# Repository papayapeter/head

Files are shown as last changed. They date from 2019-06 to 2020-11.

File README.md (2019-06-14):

# head
a head that moves it's face and breathes

documentation: [https://zenogries.com/portfolio/iamnotyourtool/](https://zenogries.com/portfolio/iamnotyourtool/)

## software
* arduino code that moves the motors and plays the sounds
* arduino code to find the minimum and maximum positions of the motors
* processing code to convert after effects tracking (of jaw and eyebrows) keyframes to an c++ array (AnimationData.h) so kind of a poor persons motion capture

## libraries
* [AccelStepper](http://www.airspayce.com/mikem/arduino/AccelStepper/) by Mike McCauley

## hardware
* [teensy 3.2](https://www.pjrc.com/teensy/teensyLC.html)
* [teensy audio adapter](https://www.pjrc.com/store/teensy3_audio.html)
* [a4988 stepper driver](https://www.pololu.com/product/1182)
* [nema 17 stepper](https://www.ebay.de/itm/Nema-17-Stepper-Motor-Schrittmotor-26Ncm-12V-0-4A-4-wire-1m-cable-3D-Printer/392163408983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)
* carrier "sceleton" designed by me
* custom circuit boards

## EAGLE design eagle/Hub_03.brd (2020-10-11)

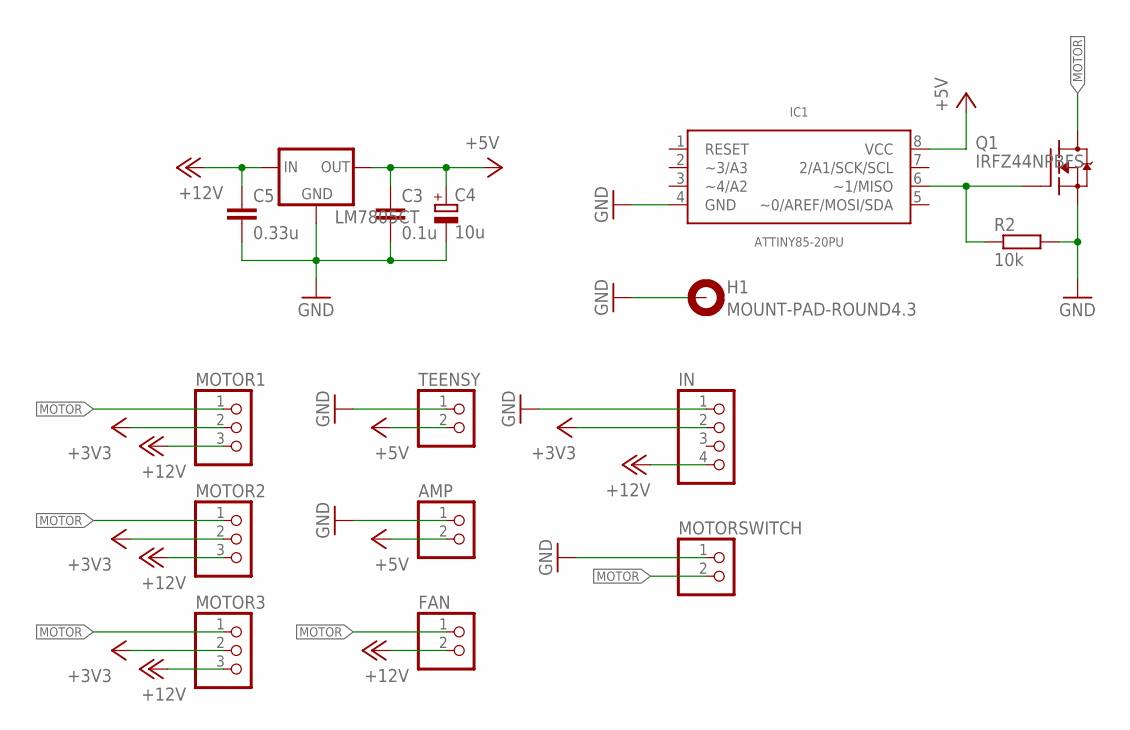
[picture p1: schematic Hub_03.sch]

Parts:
AMP: PINHD-1X2; 1X02
C3: 0.1u; C025-024X044
C4: 10u; E2,5-6E
C5: 0.33u; C025-024X044
FAN: PINHD-1X2; 1X02
H1: MOUNT-PAD-ROUND4.3; 4,3-PAD
IC1: ATTINY85-20PU; DIP08
IN: PINHD-1X4; 1X04
LM7805CT: 78XXS
MOTOR1, MOTOR2, MOTOR3: PINHD-1X3; 1X03
MOTORSWITCH: PINHD-1X2; 1X02
Q1: IRFZ44NPBFS; TO220-3S
R2: 10k; 0204/7
TEENSY: PINHD-1X2; 1X02

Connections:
+3V3: IN.2, MOTOR1.2, MOTOR2.2, MOTOR3.2
+5V: AMP.2, C3.1, C4.+, IC1.8 (VCC), LM7805CT.OUT, TEENSY.2
+12V: C5.1, FAN.2, IN.4, LM7805CT.IN, MOTOR1.3, MOTOR2.3, MOTOR3.3
GND: AMP.1, C3.2, C4.-, C5.2, H1.B4,3, IC1.4 (GND), IN.1, LM7805CT.GND, MOTORSWITCH.1, Q1.S, R2.2, TEENSY.1
MOTOR: FAN.1, MOTOR1.1, MOTOR2.1, MOTOR3.1, MOTORSWITCH.2, Q1.D
unnamed: IC1.6 (~1/MISO), Q1.G, R2.1

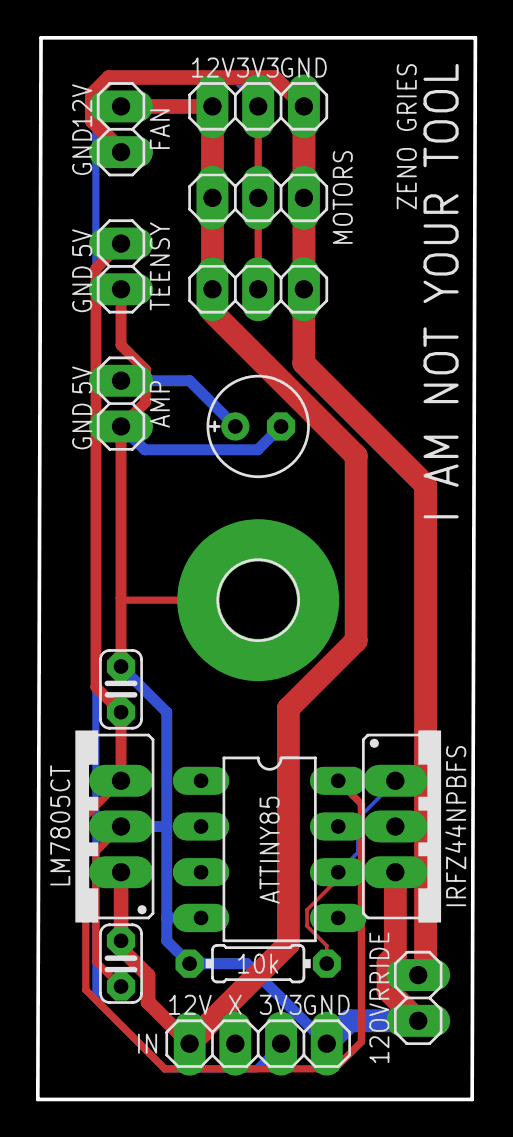
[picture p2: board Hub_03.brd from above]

Board: 2 copper layers, 24.3 x 59.0 mm, 16 parts (0 on the bottom side), 6 nets.

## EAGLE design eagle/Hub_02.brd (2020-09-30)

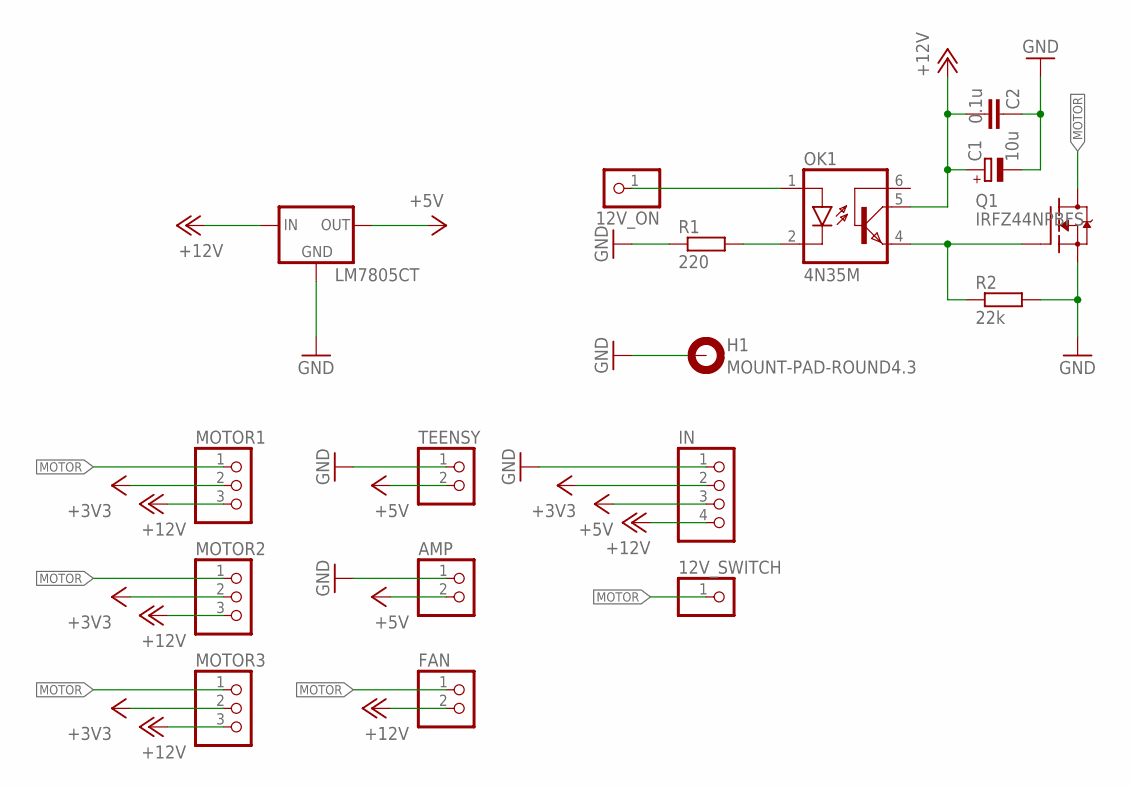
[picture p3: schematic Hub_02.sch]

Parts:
12V_ON, 12V_SWITCH: PINHD-1X1; 1X01
AMP: PINHD-1X2; 1X02
C1: 10u; E2,5-6E
C2: 0.1u; C025-024X044
FAN: PINHD-1X2; 1X02
H1: MOUNT-PAD-ROUND4.3; 4,3-PAD
IN: PINHD-1X4; 1X04
LM7805CT: 78XXS
MOTOR1, MOTOR2, MOTOR3: PINHD-1X3; 1X03
OK1: 4N35M; DIL06
Q1: IRFZ44NPBFS; TO220-3S
R1: 220; 0204/7
R2: 22k; 0204/7
TEENSY: PINHD-1X2; 1X02

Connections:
+3V3: IN.2, MOTOR1.2, MOTOR2.2, MOTOR3.2
+5V: AMP.2, IN.3, LM7805CT.OUT, TEENSY.2
+12V: C1.+, C2.2, FAN.2, IN.4, LM7805CT.IN, MOTOR1.3, MOTOR2.3, MOTOR3.3, OK1.5 (COL)
GND: AMP.1, C1.-, C2.1, H1.B4,3, IN.1, LM7805CT.GND, Q1.S, R1.1, R2.2, TEENSY.1
MOTOR: 12V_SWITCH.1, FAN.1, MOTOR1.1, MOTOR2.1, MOTOR3.1, Q1.D
unnamed: OK1.2 (C), R1.2
unnamed: OK1.4 (EMI), Q1.G, R2.1
unnamed: 12V_ON.1, OK1.1 (A)

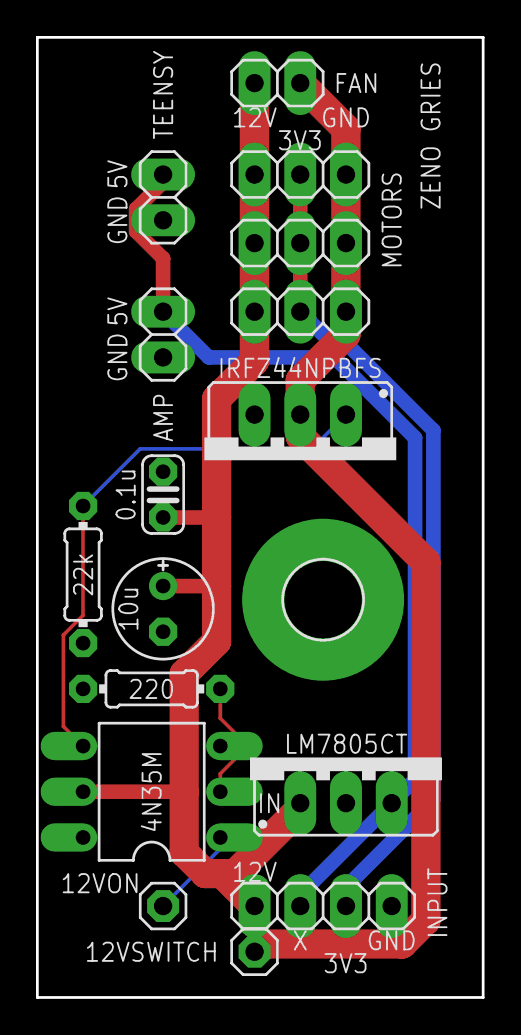
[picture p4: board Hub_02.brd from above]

Board: 2 copper layers, 24.8 x 53.3 mm, 17 parts (0 on the bottom side), 8 nets.

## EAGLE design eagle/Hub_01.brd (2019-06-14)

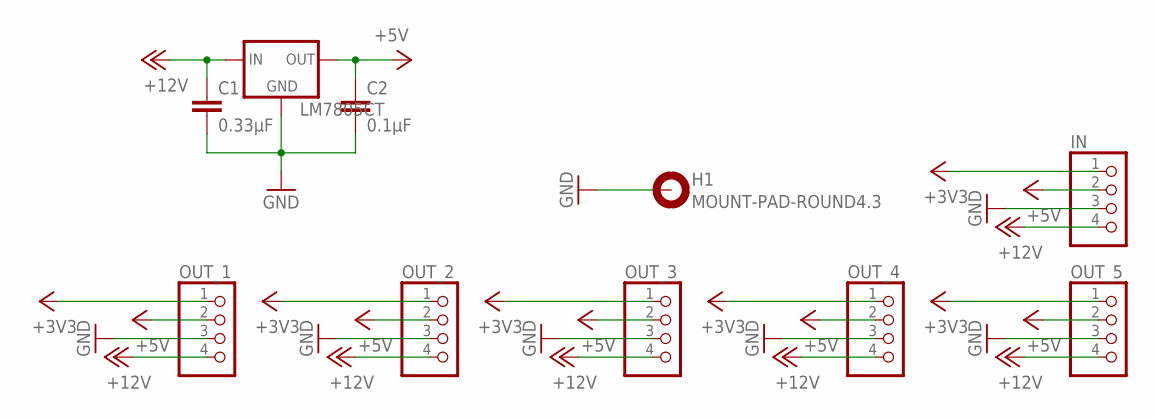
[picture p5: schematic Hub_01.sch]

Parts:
C1: 0.33µF; C025-024X044
C2: 0.1µF; C025-024X044
H1: MOUNT-PAD-ROUND4.3; 4,3-PAD
IN: PINHD-1X4; 1X04
LM7805CT: 78XXS
OUT_1, OUT_2, OUT_3, OUT_4, OUT_5: PINHD-1X4; 1X04

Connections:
+3V3: IN.1, OUT_1.1, OUT_2.1, OUT_3.1, OUT_4.1, OUT_5.1
+5V: C2.1, IN.2, LM7805CT.OUT, OUT_1.2, OUT_2.2, OUT_3.2, OUT_4.2, OUT_5.2
+12V: C1.1, IN.4, LM7805CT.IN, OUT_1.4, OUT_2.4, OUT_3.4, OUT_4.4, OUT_5.4
GND: C1.2, C2.2, H1.B4,3, IN.3, LM7805CT.GND, OUT_1.3, OUT_2.3, OUT_3.3, OUT_4.3, OUT_5.3

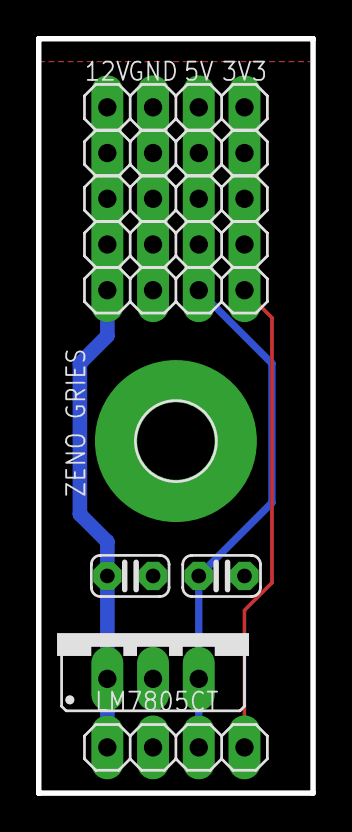
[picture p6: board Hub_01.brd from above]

Board: 2 copper layers, 15.2 x 41.9 mm, 10 parts (0 on the bottom side), 4 nets.

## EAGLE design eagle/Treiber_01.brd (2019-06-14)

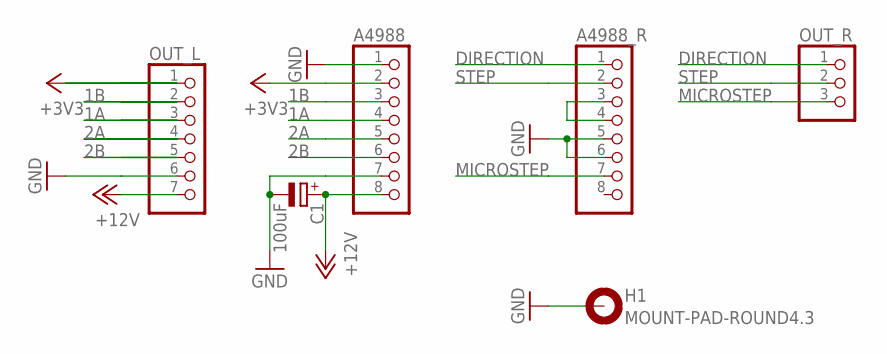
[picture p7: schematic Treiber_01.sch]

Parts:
A4988, A4988_R: PINHD-1X8; 1X08
C1: 100uF; E3,5-8
H1: MOUNT-PAD-ROUND4.3; 4,3-PAD
OUT_L: PINHD-1X7; 1X07
OUT_R: PINHD-1X3; 1X03

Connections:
1A: A4988.4, OUT_L.3
1B: A4988.3, OUT_L.2
2A: A4988.5, OUT_L.4
2B: A4988.6, OUT_L.5
+3V3: A4988.2, OUT_L.1
+12V: A4988.8, C1.+, OUT_L.7
DIRECTION: A4988_R.1, OUT_R.1
GND: A4988.1, A4988.7, A4988_R.5, A4988_R.6, C1.-, H1.B4,3, OUT_L.6
MICROSTEP: A4988_R.7, OUT_R.3
unnamed: A4988_R.3, A4988_R.4
STEP: A4988_R.2, OUT_R.2

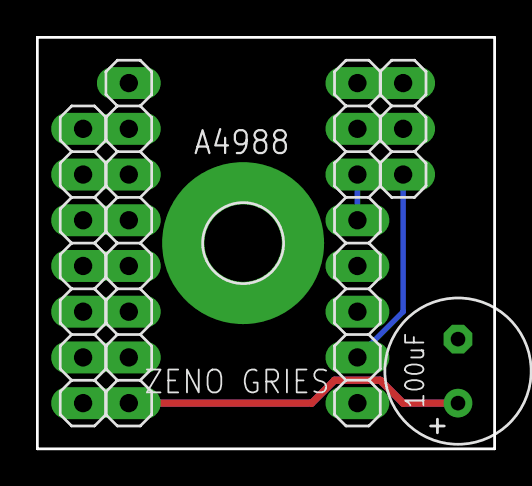
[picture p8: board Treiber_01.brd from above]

Board: 2 copper layers, 25.4 x 22.9 mm, 6 parts (0 on the bottom side), 11 nets.

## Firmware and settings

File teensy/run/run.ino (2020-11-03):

#include <AccelStepper.h>

#include "Animation_Data.h"

// ----------------------------- Audio -----------------------------
#include <Audio.h>
#include <Wire.h>
#include <SPI.h>
#include <SD.h>
#include <SerialFlash.h>

AudioPlaySdWav           playWav1;
AudioAmplifier           amp1;
AudioOutputI2S           audioOutput;
AudioConnection          patchCord1(playWav1, 0, amp1, 0);
AudioConnection          patchCord2(amp1, 0, audioOutput, 0);
AudioControlSGTL5000     sgtl5000_1;

// Pins für die SD-Karte
#define SDCARD_CS_PIN    10
#define SDCARD_MOSI_PIN  7
#define SDCARD_SCK_PIN   14

bool Play_Audio = false;

// ---------------------------- Motoren ----------------------------
// Pins zur Motorsteuerung
#define L_Augenbraue_Step 26
#define L_Augenbraue_Dir  31
#define R_Augenbraue_Step 28
#define R_Augenbraue_Dir  29
#define Kiefer_Step       27
#define Kiefer_Dir        30
#define Microstepping     32
#define Switch            25

#define LED               13

// Motoren
AccelStepper L_Augenbraue(1, L_Augenbraue_Step, L_Augenbraue_Dir);
AccelStepper R_Augenbraue(1, R_Augenbraue_Step, R_Augenbraue_Dir);
AccelStepper Kiefer(1, Kiefer_Step, Kiefer_Dir);

// Bewegunsbereiche Festlegen
const int L_Augenbraue_Min = -110, L_Augenbraue_Max = 0;        // --------- ÄNDERN
const int R_Augenbraue_Min = 110, R_Augenbraue_Max = 0;         // --------- ÄNDERN
const int Kiefer_Min = -20, Kiefer_Max = 10;                   // --------- ÄNDERN

// Zeit-Variablen
int Counter = 0;
unsigned int Interval = 1000 / FPS;
unsigned long previousMillis = 0;

// ----------------------------- SETUP -----------------------------
void setup()
{
  // -------------------------- Motoren ----------------------------
  // Pinmodes definieren
  pinMode(Microstepping, OUTPUT);
  pinMode(Switch, INPUT_PULLUP);
  pinMode(LED, OUTPUT);

  // Microstepping einschalten
  digitalWrite(Microstepping, HIGH);

  // Beschleunigung hoch setzten
  L_Augenbraue.setAcceleration(5000);   // GLÄTTUNG --------- ÄNDERN
  R_Augenbraue.setAcceleration(5000);   // GLÄTTUNG --------- ÄNDERN
  Kiefer.setAcceleration(5000);         // GLÄTTUNG --------- ÄNDERN

  // --------------------------- Audio -----------------------------
  Serial.begin(9600);

  AudioMemory(8);

  // Audio - Lautstärke
  sgtl5000_1.enable();
  sgtl5000_1.volume(0.32); // Kopfhörer Lautstärke??
  amp1.gain(0.32);
  //sgtl5000_1.lineOutLevel(27);

  // SD-Karten - Kommunikation initiieren
  SPI.setMOSI(SDCARD_MOSI_PIN);
  SPI.setSCK(SDCARD_SCK_PIN);
  if (!(SD.begin(SDCARD_CS_PIN))) {
    // Hier das Programm beenden und nur noch diese Nachricht ausgeben
    while (1)
    {
      Serial.println("Die SD-Karte ist doof!");
      digitalWrite(LED, HIGH);
      delay(500);
      digitalWrite(LED, LOW);
      delay(500);
    }
  }
}

// ----------------------------- LOOP ------------------------------
void loop()
{
  if (!digitalRead(Switch))
  {
    // Animation und Audio in Schleife Abspielen, wenn der Schalter an ist
    if (!Play_Audio && getAnimationTime() == 0)
    {
      Play_Audio = true;
      playWav1.play("ATMEN_01.WAV");
    }
    // Das Audio neustarten, wenn Animation vorbei ist
    if (Play_Audio && getAnimationTime() == Animation_Length - 1)
    {
      Play_Audio = false;
      playWav1.stop();
    }
    digitalWrite(LED, LOW);
    runAnimation();
  }
  else
  {
    // Alles auf 0 zurücksetzten und Audio stoppen
    toZero();
    setAnimationTime(0);
    if (Play_Audio)
    {
      Play_Audio = false;
      digitalWrite(LED, HIGH);
      playWav1.stop();
    }
  }
}

// Funktionen
void toZero()
{
  L_Augenbraue.setMaxSpeed(200);
  R_Augenbraue.setMaxSpeed(200);
  Kiefer.setMaxSpeed(200);
  L_Augenbraue.moveTo(0);
  R_Augenbraue.moveTo(0);
  Kiefer.moveTo(0);

  L_Augenbraue.run();
  R_Augenbraue.run();
  Kiefer.run();
}
void setAnimationTime(int Frames)
{
  Counter = Frames;
}
void runAnimation()
{
  unsigned long currentMillis = millis();
  if (currentMillis - previousMillis >= Interval)
  {
    previousMillis = currentMillis;

    Serial.println("KieferS: " + String(map(Animation_Sequence[Counter][2], 0, 255, Kiefer_Min, Kiefer_Max)) +
                   "\tKieferI: " + String(Kiefer.currentPosition()) +
                   "\tFrame: " + String(Counter) +
                   "\tAudio: " + String(float(playWav1.positionMillis()) / 1000.0f) +
                   "\tSekunden: " + String(float(millis()) / 1000.0f));

    Counter++;
    if (Counter >= Animation_Length)
    {
      Counter = 0;
    }

    int L_Augenbraue_Target = map(Animation_Sequence[Counter][0], 0, 255, L_Augenbraue_Min, L_Augenbraue_Max);
    int R_Augenbraue_Target = map(Animation_Sequence[Counter][1], 0, 255, R_Augenbraue_Min, R_Augenbraue_Max);
    int Kiefer_Target = map(Animation_Sequence[Counter][2], 0, 255, Kiefer_Min, Kiefer_Max);
    L_Augenbraue.setMaxSpeed(norm(L_Augenbraue_Target - L_Augenbraue.currentPosition()) * FPS);
    R_Augenbraue.setMaxSpeed(norm(R_Augenbraue_Target - R_Augenbraue.currentPosition()) * FPS);
    Kiefer.setMaxSpeed(norm(Kiefer_Target - Kiefer.currentPosition()) * FPS);
    L_Augenbraue.moveTo(L_Augenbraue_Target);
    R_Augenbraue.moveTo(R_Augenbraue_Target);
    Kiefer.moveTo(Kiefer_Target);
  }

  L_Augenbraue.run();
  R_Augenbraue.run();
  Kiefer.run();
}

int getAnimationTime()
{
  return Counter;
}

int norm(int i)
{
  if (i < 0)
    return i * (-1);
  else
    return i;
}

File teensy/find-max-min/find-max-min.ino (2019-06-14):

#include <AccelStepper.h>

// ---------------------------- Motoren ----------------------------
// Pins zur Motorsteuerung
#define L_Augenbraue_Step 26
#define L_Augenbraue_Dir  31
#define R_Augenbraue_Step 28
#define R_Augenbraue_Dir  29
#define Kiefer_Step       27
#define Kiefer_Dir        30
#define Microstepping     32
#define Switch            25

#define LED               13

// Motoren
AccelStepper L_Augenbraue(1, L_Augenbraue_Step, L_Augenbraue_Dir);
AccelStepper R_Augenbraue(1, R_Augenbraue_Step, R_Augenbraue_Dir);
AccelStepper Kiefer(1, Kiefer_Step, Kiefer_Dir);

// Bewegunsbereiche Festlegen                                     ---!!!---
const int L_Augenbraue_Min = -120, L_Augenbraue_Max = 0;        // ÄNDERN
const int R_Augenbraue_Min = 120, R_Augenbraue_Max = 0;        // ÄNDERN
const int Kiefer_Min = -150, Kiefer_Max = 70;                    // ÄNDERN

boolean L_Augenbraue_Positiv = false, R_Augenbraue_Positiv = false, Kiefer_Positiv = false;

// ----------------------------- SETUP -----------------------------
void setup()
{
  // -------------------------- Motoren ----------------------------
  // Pinmodes definieren
  pinMode(Microstepping, OUTPUT);
  pinMode(Switch, INPUT_PULLUP);
  pinMode(LED, OUTPUT);

  // Microstepping einschalten
  digitalWrite(Microstepping, HIGH);
  
  // Beschleunigung hoch setzten
  L_Augenbraue.setAcceleration(10000);
  R_Augenbraue.setAcceleration(10000);
  Kiefer.setAcceleration(10000);
}

// ----------------------------- LOOP ------------------------------
void loop()
{
  if (!digitalRead(Switch))
  {
    L_Augenbraue.setMaxSpeed(50);
    R_Augenbraue.setMaxSpeed(50);
    Kiefer.setMaxSpeed(50);
    L_Augenbraue.moveTo(L_Augenbraue_Min);
    R_Augenbraue.moveTo(R_Augenbraue_Min);
    Kiefer.moveTo(Kiefer_Min);
    L_Augenbraue.run();
    R_Augenbraue.run();
    Kiefer.run();
//    runAnimation();
    digitalWrite(LED, LOW);
  }
  else
  {
    toZero();
    digitalWrite(LED, HIGH);
  }
}

// Funktionen
void toZero()
{
  L_Augenbraue.setMaxSpeed(200);
  R_Augenbraue.setMaxSpeed(200);
  Kiefer.setMaxSpeed(200);
  L_Augenbraue.moveTo(0);
  R_Augenbraue.moveTo(0);
  Kiefer.moveTo(0);

  L_Augenbraue.run();
  R_Augenbraue.run();
  Kiefer.run();
}
void runAnimation()
{
  L_Augenbraue.setMaxSpeed(50);
  R_Augenbraue.setMaxSpeed(50);
  Kiefer.setMaxSpeed(50);

  // linke Augenbraue
  if (L_Augenbraue.currentPosition() == 0)
  {
    if (L_Augenbraue_Positiv)
    {
      L_Augenbraue.moveTo(L_Augenbraue_Max);
    }
    else
    {
      L_Augenbraue.moveTo(L_Augenbraue_Min);
    }
  }
  else if (L_Augenbraue.currentPosition() == L_Augenbraue_Min)
  {
    L_Augenbraue_Positiv = true;
    L_Augenbraue.moveTo(0);
  }
  else if (L_Augenbraue.currentPosition() == L_Augenbraue_Max)
  {
    L_Augenbraue_Positiv = false;
    L_Augenbraue.moveTo(0);
  }
  // rechte Augenbraue
  if (R_Augenbraue.currentPosition() == 0)
  {
    if (R_Augenbraue_Positiv)
    {
      R_Augenbraue.moveTo(R_Augenbraue_Max);
    }
    else
    {
      R_Augenbraue.moveTo(R_Augenbraue_Min);
    }
  }
  else if (R_Augenbraue.currentPosition() == R_Augenbraue_Min)
  {
    R_Augenbraue_Positiv = true;
    R_Augenbraue.moveTo(0);
  }
  else if (R_Augenbraue.currentPosition() == R_Augenbraue_Max)
  {
    R_Augenbraue_Positiv = false;
    R_Augenbraue.moveTo(0);
  }
  // Kiefer
  if (Kiefer.currentPosition() == 0)
  {
    if (Kiefer_Positiv)
    {
      Kiefer.moveTo(Kiefer_Max);
    }
    else
    {
      Kiefer.moveTo(Kiefer_Min);
    }
  }
  else if (Kiefer.currentPosition() == Kiefer_Min)
  {
    Kiefer_Positiv = true;
    Kiefer.moveTo(0);
  }
  else if (Kiefer.currentPosition() == Kiefer_Max)
  {
    Kiefer_Positiv = false;
    Kiefer.moveTo(0);
  }

  L_Augenbraue.run();
  R_Augenbraue.run();
  Kiefer.run();
}

int norm(int i)
{
  if (i < 0)
    return i * (-1);
  else
    return i;
}

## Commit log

2020-09-30 added new hub version
    [Hub_02.brd, Hub_02.sch]
2020-10-03 added new hub with attiny
    [Hub_03.brd, Hub_03.sch]
2020-10-11 added new hub
    [Hub_03.brd]
2020-10-27 corrected timing & and wrong memory access
    [run.ino]
